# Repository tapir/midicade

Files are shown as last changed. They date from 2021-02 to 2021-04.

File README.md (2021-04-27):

Midicade
--------

An ATMega32U4 based Midi Fighter clone

Dependencies
------------

* ezButton
* MIDIUSB
* FastLED
* LibPrintf (Used only in debug mode)

TODO
----

- Fixed: Bottom enclosure flex
- Fixed: Enclosure bototm/top mating tolerances
- Fixed: Small fixes to make it suitable for FDM printing
- Fixed: Reset circuit
- Find better rubber feet (too soft)
- Clean up software to bare minimum
- Document EEPROM structure and default values
- Document general hardware info
- Include STEP files and put a link to OnShape files
- Change to Sparkfun or Polulu bootloader to get rid of the 8 second boot delay

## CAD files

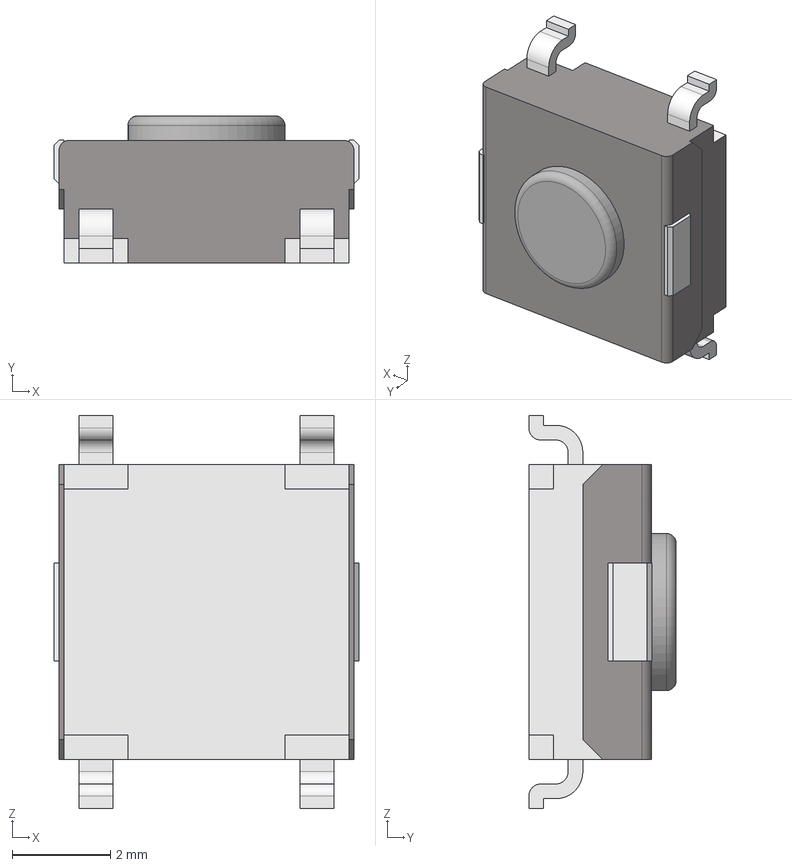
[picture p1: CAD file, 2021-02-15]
hardware/Resources/Omron_B3FS-1000P.step
6.20 x 3.00 x 8.00 mm

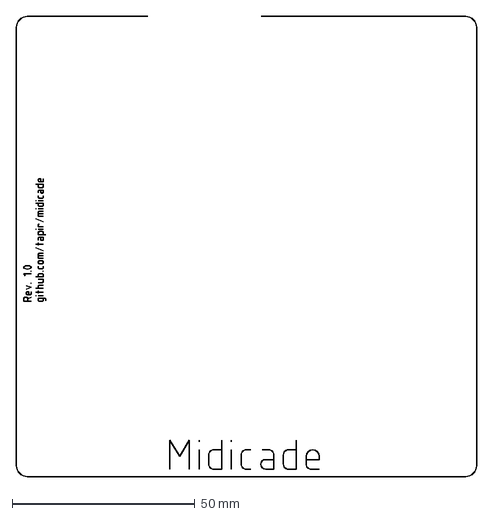
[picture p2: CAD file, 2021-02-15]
hardware/Resources/Front_Silk.dxf
126.0 x 126.0 mm

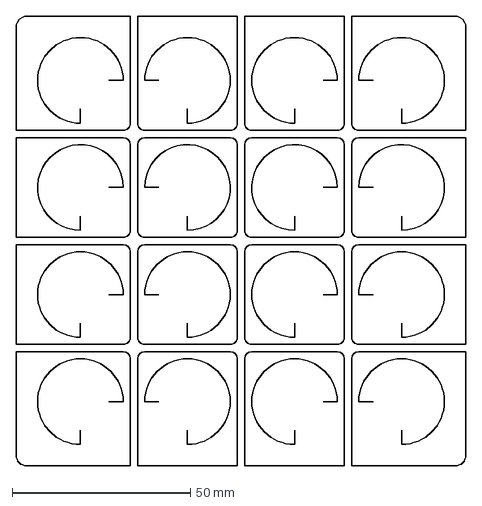
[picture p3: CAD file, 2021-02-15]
hardware/Resources/Back_Silk.dxf
126.0 x 126.0 mm

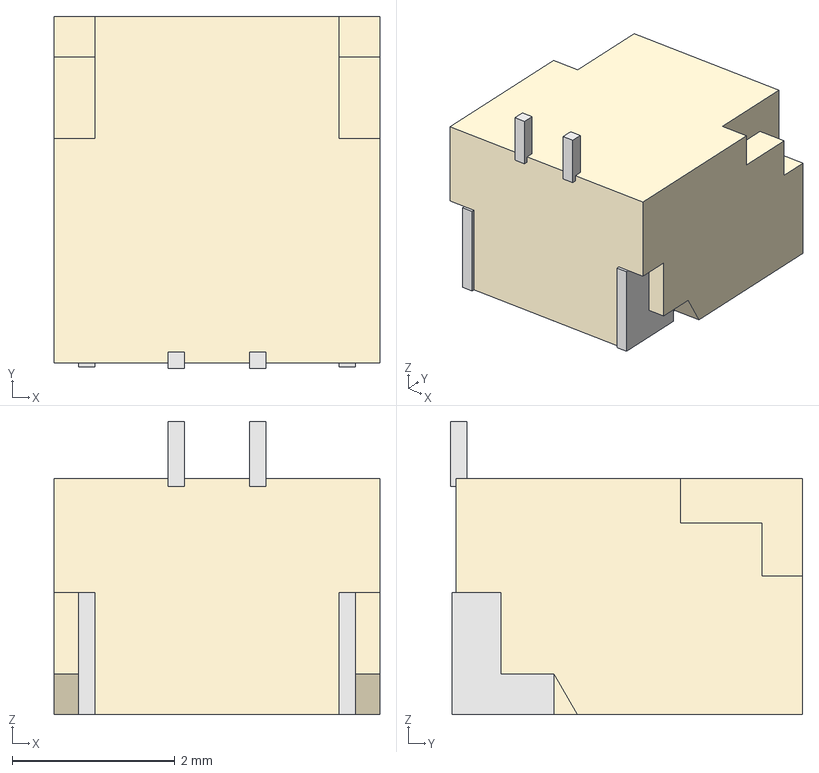
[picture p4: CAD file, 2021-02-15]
hardware/Resources/JST_BM02B-SRSS-TB.step
4.00 x 4.32 x 3.60 mm

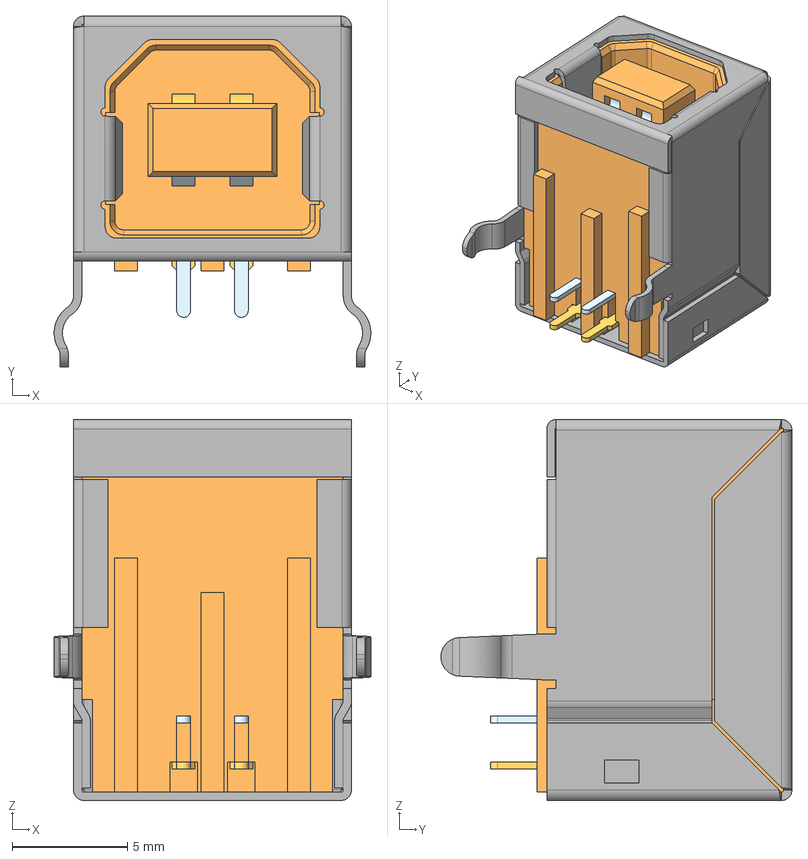
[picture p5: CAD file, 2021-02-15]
hardware/Resources/USB_Type_B.step
13.7 x 15.2 x 16.5 mm
usb btm contact x 2
usb top contact x 2
USB SHELL
USB core

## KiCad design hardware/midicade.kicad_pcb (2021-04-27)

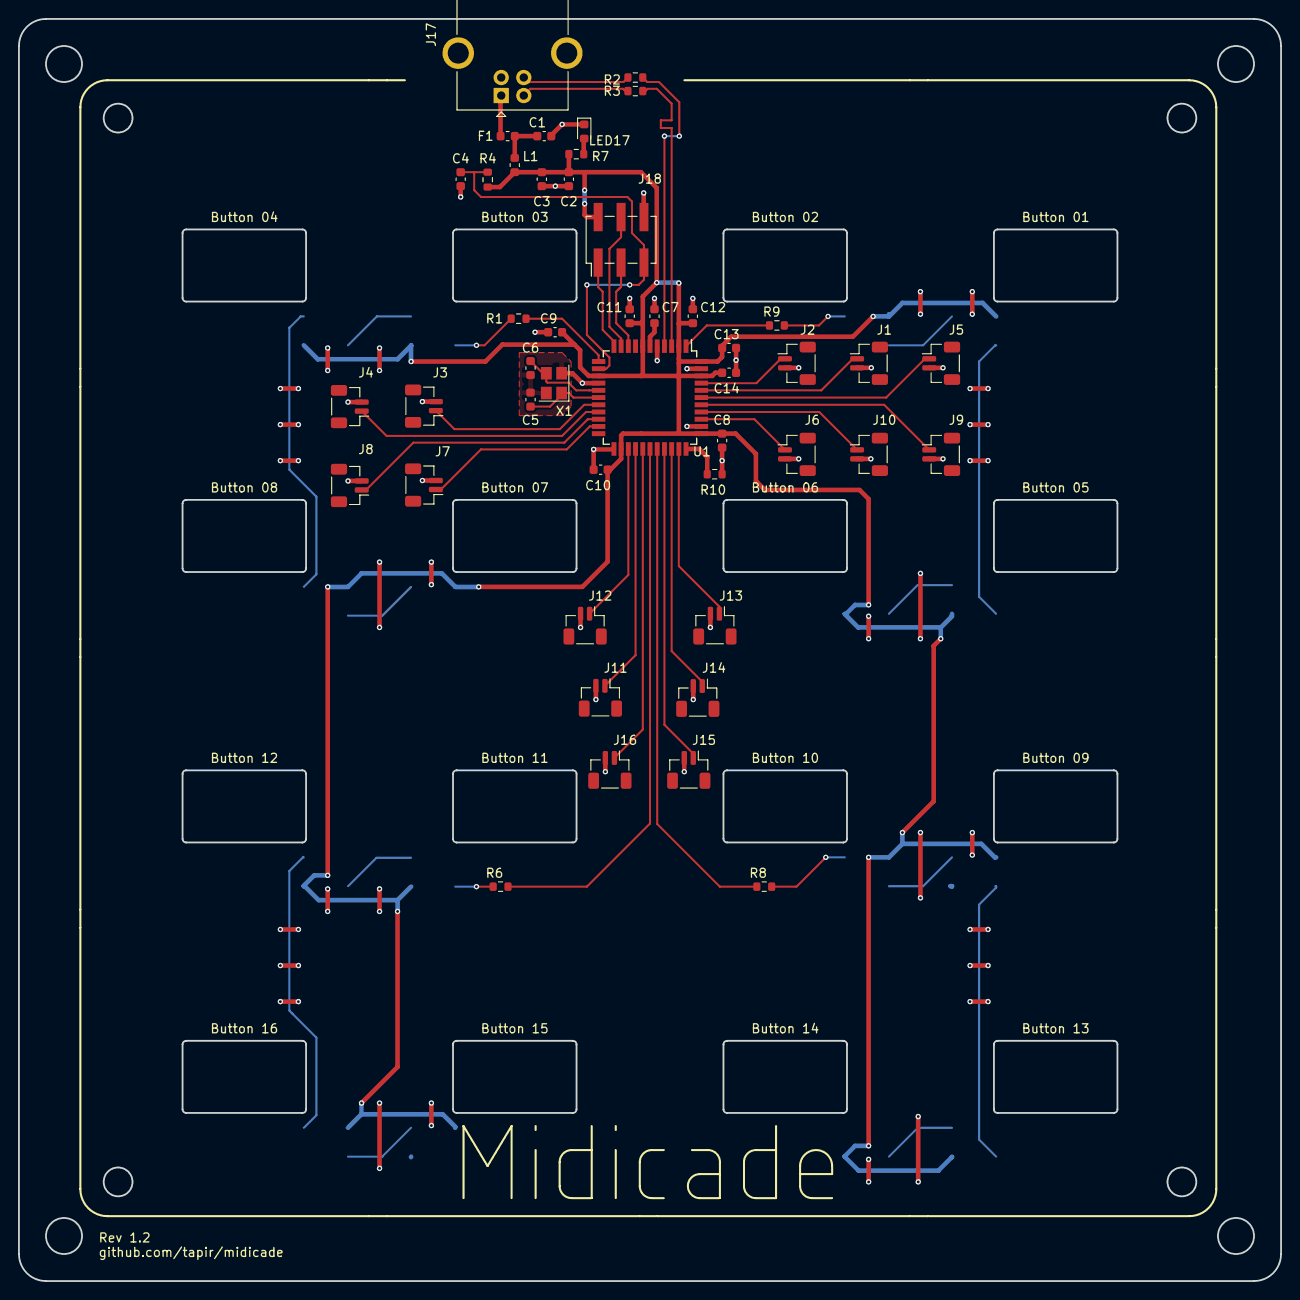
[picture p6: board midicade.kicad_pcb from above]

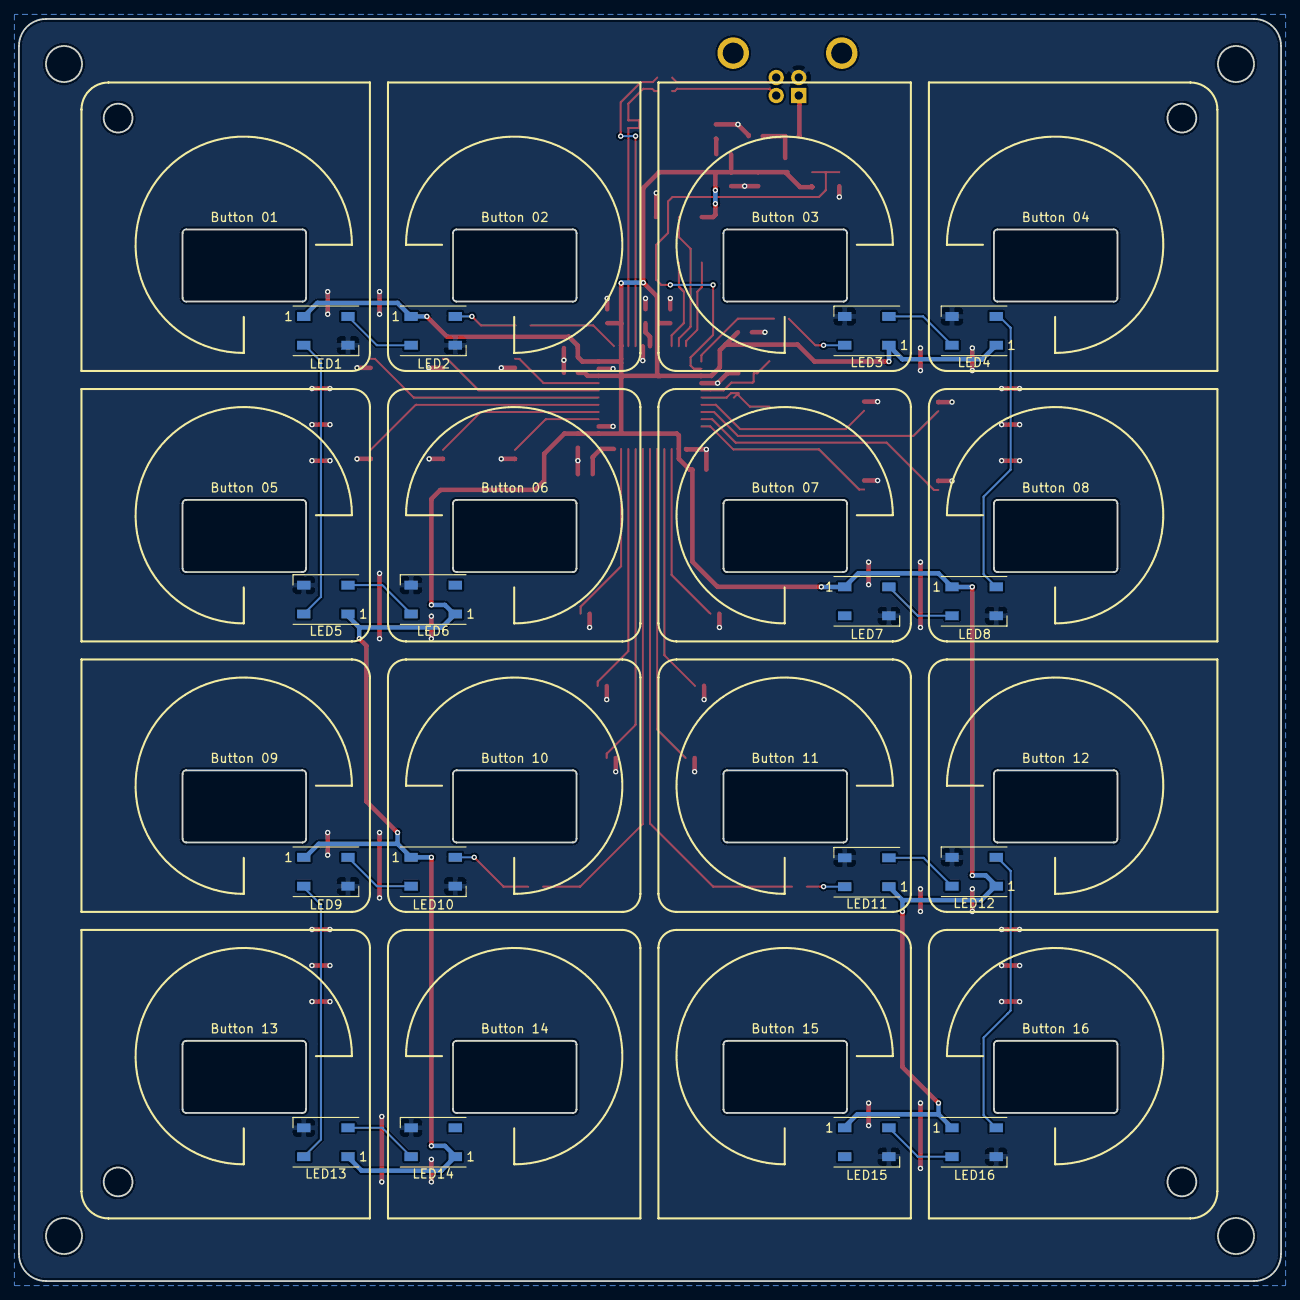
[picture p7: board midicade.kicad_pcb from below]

Board: 2 copper layers, 140.0 x 140.0 mm, 62 parts (16 on the bottom side), 53 nets.

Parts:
C1: 10nF; C_0603_1608Metric
C2, C4, C8, C9, C10, C11, C12, C13, C14: 100nF; C_0603_1608Metric
C3: 10uF; C_0603_1608Metric
C5, C6: 22pF; C_0603_1608Metric
C7: 1uF; C_0603_1608Metric
F1: 0603L050; Fuse_0603_1608Metric
J1, J2, J3, J4, J5, J6, J7, J8, J9, J10, J11, J12, J13, J14, J15, J16: Conn_01x02; JST_SH_BM02B-SRSS-TB_1x02-1MP_P1.00mm_Vertical_3D
J17: USB_B; USB_B_OST_USB-B1HSxx_Horizontal_3D
J18: Conn_01x06; PinHeader_2x03_P2.54mm_Vertical_SMD
L1: BLM18PG300SN1D; L_0603_1608Metric
LED1, LED2, LED3, LED4, LED5, LED6, LED7, LED8, LED9, LED10, LED11, LED12, LED13, LED14, LED15, LED16: WS2812B-V5; LED_WS2812B_PLCC4_5.0x5.0mm_P3.2mm
LED17: LED; LED_0603_1608Metric
R1, R6, R8, R9: 330; R_0603_1608Metric
R2, R3: 22; R_0603_1608Metric
R4, R10: 10K; R_0603_1608Metric
R7: 470; R_0603_1608Metric
U1: ATmega32U4; TQFP-44_10x10mm_P0.8mm
X1: ±10ppm 12pF; Crystal_SMD_3225-4Pin_3.2x2.5mm

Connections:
+5V: C2.1, C3.1, C8.1, C9.1, C10.1, C11.1, C12.1, C13.1, C14.1, J18.2, L1.2, LED1.1, LED2.1, LED3.1, LED4.1, LED5.1, LED6.1, LED7.1, LED8.1, LED9.1, LED10.1, LED11.1, LED12.1, LED13.1, LED14.1, LED15.1, LED16.1, R4.2, R7.1, U1.2, U1.7, U1.14, U1.24, U1.34, U1.42, U1.44
/D0: J8.1, U1.20
/D1: J7.1, U1.21
/D2: J4.1, U1.19
/D3: J3.1, U1.18
/D4: J12.1, U1.25
/D5: J14.1, U1.31
/D6: J16.1, U1.27
/D7: R9.2, U1.1
/D8: R6.2, U1.28
/D9: R8.2, U1.29
/D10: J15.1, U1.30
/D11: R1.2, U1.12
/D12: J11.1, U1.26
/D13: J13.1, U1.32
/D18: J6.1, U1.36
/D19: J10.1, U1.37
/D20: J9.1, U1.38
/D21: J5.1, U1.39
/D22: J1.1, U1.40
/D23: J2.1, U1.41
/DN: R3.1, U1.3
/DP: R2.2, U1.4
/MISO: J18.1, U1.11
/MOSI: J18.4, U1.10
/RESET: C4.1, J18.5, R4.1, U1.13
/SCK: J18.3, U1.9
GND: C1.2, C2.2, C3.2, C4.2, C5.2, C6.2, C7.2, C8.2, C9.2, C10.2, C11.2, C12.2, C13.2, C14.2, J1.2, J2.2, J3.2, J4.2, J5.2, J6.2, J7.2, J8.2, J9.2, J10.2, J11.2, J12.2, J13.2, J14.2, J15.2, J16.2, J17.4, J18.6, LED1.3, LED2.3, LED3.3, LED4.3, LED5.3, LED6.3, LED7.3, LED8.3, LED9.3, LED10.3, LED11.3, LED12.3, LED13.3, LED14.3, LED15.3, LED16.3, LED17.1, R10.1, U1.5, U1.15, U1.23, U1.35, U1.43, X1.2, X1.4
unnamed: C1.1, F1.2, L1.1
unnamed: C5.1, U1.17, X1.1
unnamed: C6.1, U1.16, X1.3
unnamed: C7.1, U1.6
unnamed: F1.1, J17.1
unnamed: J17.2, R3.2
unnamed: J17.3, R2.1
unnamed: LED1.2, LED5.4
unnamed: LED1.4, LED2.2
unnamed: LED2.4, R9.1
unnamed: LED3.2, LED4.4
unnamed: LED3.4, R1.1
unnamed: LED4.2, LED8.4
unnamed: LED5.2, LED6.4
unnamed: LED7.4, LED8.2
unnamed: LED9.4, LED10.2
unnamed: LED10.4, R8.1
unnamed: LED11.2, LED12.4
unnamed: LED11.4, R6.1
unnamed: LED12.2, LED16.4
unnamed: LED13.2, LED14.4
unnamed: LED9.2, LED13.4
unnamed: LED15.4, LED16.2
unnamed: LED17.2, R7.2
unnamed: R10.2, U1.33

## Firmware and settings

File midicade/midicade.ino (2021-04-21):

// Copyright © 2021 Cosku Bas. All rights reserved.
// Use of this source code is governed by a BSD-style
// license that can be found in the LICENSE.md file.

#include "debug.h"
#include "device.h"

Device* midicade;

void setup() {
    DEBUG_INIT();
    DEBUG_PRINTF("Midicade has been started in debug mode\n");
    midicade = new Device();
}

void loop() {
    midicade->UpdateState();
}

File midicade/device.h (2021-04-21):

// Copyright © 2021 Cosku Bas. All rights reserved.
// Use of this source code is governed by a BSD-style
// license that can be found in the LICENSE.md file.

#ifndef __DEVICE_H__
#define __DEVICE_H__

#include <FastLED.h>
#include <ezButton.h>
#include <stdint.h>

// Status codes
#define CONFIG_DEFAULT 0xFD
#define CONFIG_CUSTOM  0xFE
#define CONFIG_RESET   0xFF

// EEPROM address offsets
#define ADDR_STATUS       0x00
#define ADDR_BASE_CHANNEL 0x01
#define ADDR_CONFIG       0x02

// Device parameters
#define DEV_BTN_DEBOUNCE   3 // miliseconds
#define DEV_MAX_BTN        16
#define DEV_LEDS_PER_ARRAY 4
#define DEV_MAX_LED_ARRAYS 4

// MIDI
#define MIDI_CHANNEL_BASE 2
#define MIDI_MAX_CHANNEL  16
#define MIDI_MAX_NOTE     127
#define MIDI_MAX_VELOCITY 127

// PINS
#define PIN_BUTTON_1    22
#define PIN_BUTTON_2    23
#define PIN_BUTTON_3    3
#define PIN_BUTTON_4    2
#define PIN_BUTTON_5    21
#define PIN_BUTTON_6    18
#define PIN_BUTTON_7    1
#define PIN_BUTTON_8    0
#define PIN_BUTTON_9    20
#define PIN_BUTTON_10   19
#define PIN_BUTTON_11   12
#define PIN_BUTTON_12   4
#define PIN_BUTTON_13   13
#define PIN_BUTTON_14   5
#define PIN_BUTTON_15   10
#define PIN_BUTTON_16   6
#define PIN_LED_ARRAY_1 7  // Array 0
#define PIN_LED_ARRAY_2 8  // Array 1
#define PIN_LED_ARRAY_3 9  // Array 2
#define PIN_LED_ARRAY_4 11 // Array 3

const uint8_t ledPinMap[DEV_MAX_BTN * 2] = {
    0, 1, // LED_01 -> Array 0, Index 1
    0, 0, // LED_02 -> Array 0, Index 0
    3, 0, // LED_03 -> Array 3, Index 0
    3, 1, // LED_04 -> Array 3, Index 1
    0, 2, // LED_05 -> Array 0, Index 2
    0, 3, // LED_06 -> Array 0, Index 3
    3, 3, // LED_07 -> Array 3, Index 3
    3, 2, // LED_08 -> Array 3, Index 2
    2, 1, // LED_09 -> Array 2, Index 1
    2, 0, // LED_10 -> Array 2, Index 0
    1, 0, // LED_11 -> Array 1, Index 0
    1, 1, // LED_12 -> Array 1, Index 1
    2, 2, // LED_13 -> Array 2, Index 2
    2, 3, // LED_14 -> Array 2, Index 3
    1, 3, // LED_15 -> Array 1, Index 3
    1, 2, // LED_16 -> Array 1, Index 2
};

// Consts
#define SET_STATUS         0x10
#define SET_BASE_CHANNEL   0x11
#define SET_COLOR_PRESSED  0x12
#define SET_COLOR_RELEASED 0x13
#define SET_MIDI_NOTE      0x14
#define SET_MIDI_VELOCITY  0x15
#define SET_MOMENTARY      0x16
#define PRG_DONE           0x17
#define PRG_ECHO           0x18
#define PRG_FETCH          0x19

class Device {
public:
    // Creates a new Midicade device
    Device();

    // Cleans everything
    ~Device();

    // Processes and updates all state: MIDI, LEDs etc...
    void UpdateState();

private:
    typedef struct btnConfig_t {
        uint8_t midiNote;
        uint8_t midiVelocity;
        CRGB    colorPressed;
        CRGB    colorReleased;
        bool    momentary; // Enable/disable CC messages
    };

    // States
    ezButton* btnStates[DEV_MAX_BTN];
    CRGB*     ledStates[DEV_MAX_BTN];
    CRGB      ledArrays[DEV_MAX_LED_ARRAYS][DEV_LEDS_PER_ARRAY];

    // Defaults
    uint8_t     noteChannel            = MIDI_CHANNEL_BASE;
    uint8_t     controlChannel         = MIDI_CHANNEL_BASE + 1;
    btnConfig_t btnConfig[DEV_MAX_BTN] = {
        { .midiNote = 48, .midiVelocity = 127, .colorPressed = CRGB::Cyan, .colorReleased = CRGB::Red, .momentary = true },    // BUTTON_01
        { .midiNote = 49, .midiVelocity = 127, .colorPressed = CRGB::Cyan, .colorReleased = CRGB::Red, .momentary = true },    // BUTTON_02
        { .midiNote = 50, .midiVelocity = 127, .colorPressed = CRGB::Cyan, .colorReleased = CRGB::Red, .momentary = true },    // BUTTON_03
        { .midiNote = 51, .midiVelocity = 127, .colorPressed = CRGB::Cyan, .colorReleased = CRGB::Red, .momentary = true },    // BUTTON_04
        { .midiNote = 44, .midiVelocity = 127, .colorPressed = CRGB::Cyan, .colorReleased = CRGB::Blue, .momentary = true },   // BUTTON_05
        { .midiNote = 45, .midiVelocity = 127, .colorPressed = CRGB::Cyan, .colorReleased = CRGB::Blue, .momentary = true },   // BUTTON_06
        { .midiNote = 46, .midiVelocity = 127, .colorPressed = CRGB::Cyan, .colorReleased = CRGB::Blue, .momentary = true },   // BUTTON_07
        { .midiNote = 47, .midiVelocity = 127, .colorPressed = CRGB::Cyan, .colorReleased = CRGB::Blue, .momentary = true },   // BUTTON_08
        { .midiNote = 40, .midiVelocity = 127, .colorPressed = CRGB::Cyan, .colorReleased = CRGB::Green, .momentary = true },  // BUTTON_09
        { .midiNote = 41, .midiVelocity = 127, .colorPressed = CRGB::Cyan, .colorReleased = CRGB::Green, .momentary = true },  // BUTTON_10
        { .midiNote = 42, .midiVelocity = 127, .colorPressed = CRGB::Cyan, .colorReleased = CRGB::Green, .momentary = true },  // BUTTON_11
        { .midiNote = 43, .midiVelocity = 127, .colorPressed = CRGB::Cyan, .colorReleased = CRGB::Green, .momentary = true },  // BUTTON_12
        { .midiNote = 36, .midiVelocity = 127, .colorPressed = CRGB::Cyan, .colorReleased = CRGB::Yellow, .momentary = true }, // BUTTON_13
        { .midiNote = 37, .midiVelocity = 127, .colorPressed = CRGB::Cyan, .colorReleased = CRGB::Yellow, .momentary = true }, // BUTTON_14
        { .midiNote = 38, .midiVelocity = 127, .colorPressed = CRGB::Cyan, .colorReleased = CRGB::Yellow, .momentary = true }, // BUTTON_15
        { .midiNote = 39, .midiVelocity = 127, .colorPressed = CRGB::Cyan, .colorReleased = CRGB::Yellow, .momentary = true }, // BUTTON_16
    };

    // Programming mode
    bool once = true;
    void runProgrammer();

    // Changes given button's LED color
    void setButtonLedPressed(uint8_t button);
    void setButtonLedReleased(uint8_t button);
    void setButtonLedColor(uint8_t button, CRGB color);

    // MIDI messages
    void midiNoteOn(uint8_t button);
    void midiNoteOff(uint8_t button);
    void midiControlOn(uint8_t button);
    void midiControlOff(uint8_t button);

    // EEPROM routines
    static void        storeButtonConfig(uint8_t button, btnConfig_t config);
    static btnConfig_t fetchButtonConfig(uint8_t button);
    static void        storeByte(uint16_t addr, uint8_t data);
    static uint8_t     fetchByte(uint16_t addr);
};

#endif

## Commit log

2021-02-15 initial hardware design
    [Back_Silk.dxf, Front_Silk.dxf, JST_BM02B-SRSS-TB.step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]
2021-02-15 minor production changes
    [midicade.kicad_pcb, midicade.sch]
2021-02-16 update LED resistor value
    [midicade.sch]
2021-03-20 fixed pin naming to match leonardo
    [midicade.sch]
2021-03-20 arduino ide config files
2021-03-20 fix board manager file name
2021-03-20 fix arduino package structure
2021-03-20 fix board group name
2021-03-20 fix boards.txt
2021-03-20 fix usb vid pid
2021-03-20 orrect bootloader and vid pid names
2021-04-27 rev 1.2 hardware
    [midicade.kicad_pcb, midicade.sch]
